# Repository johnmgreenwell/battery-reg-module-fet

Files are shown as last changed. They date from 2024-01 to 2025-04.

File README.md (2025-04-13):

# Battery Regulator Module (N-FET Version)

Custom lithium-polymer battery voltage monitor and regulator module (N-FET version).

## Overview

This custom module is designed as a drop-in for small-scale electronics projects providing 3.3V linear regulated voltage output from a raw lithium polymer cell input. The battery input voltage is monitored by the [MIC2779](https://www.digikey.com/en/products/detail/microchip-technology/MIC2779L-2YM5-TR/1616864) whose output enables or disables the regulated output supply. It is configured with hysteresis to cutoff output when the battery voltage reaches 3.1V and to then hold in reset until the battery voltage exceeds 3.6V.

This is a form-factor-compatible replacement for the battery regulator module design available [here](https://github.com/johnmgreenwell/battery-reg-module). This version makes use of an N-FET transistor for switching rather than the built-in enable used in the original design. This version is meant to serve as a alternate to be used on the basis of parts-available.

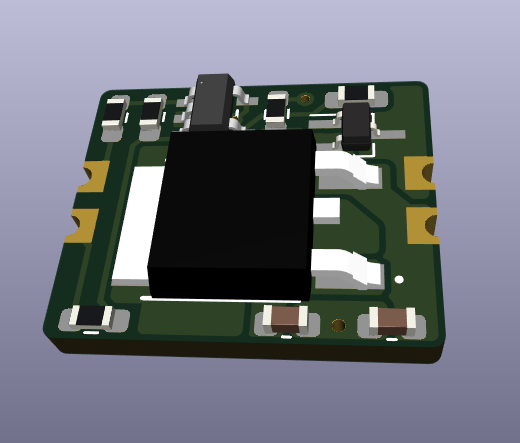
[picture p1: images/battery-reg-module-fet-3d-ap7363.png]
Battery Regulator Module 3d Render


The module supports the 1.5A maximum current limitations of the regulator chip [AP7363](https://www.digikey.com/en/products/detail/diodes-incorporated/AP7363-33D-13/3829401) used.

This module may be combined with a Lipo charger module such as the [TP4056](https://www.best-microcontroller-projects.com/tp4056.html) (along with any in-circuit charging mods as required) for a complete custom battery charging/monitoring/regulation for small-scale electronics projects.

The zipped gerber files provided may be uploaded to a PCB manufacturer for fabrication. Below is the automatic rendering of the uploaded gerbers by [OSHPark](https://oshpark.com/home).

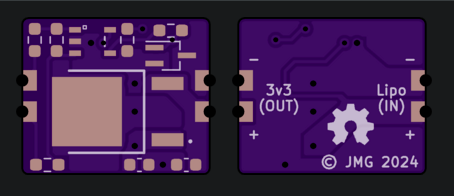
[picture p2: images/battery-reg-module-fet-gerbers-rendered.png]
Battery Regulator Module FET Gerbers Rendered


## Schematic

The schematic for the circuit is provided below as designed in Kicad 9.

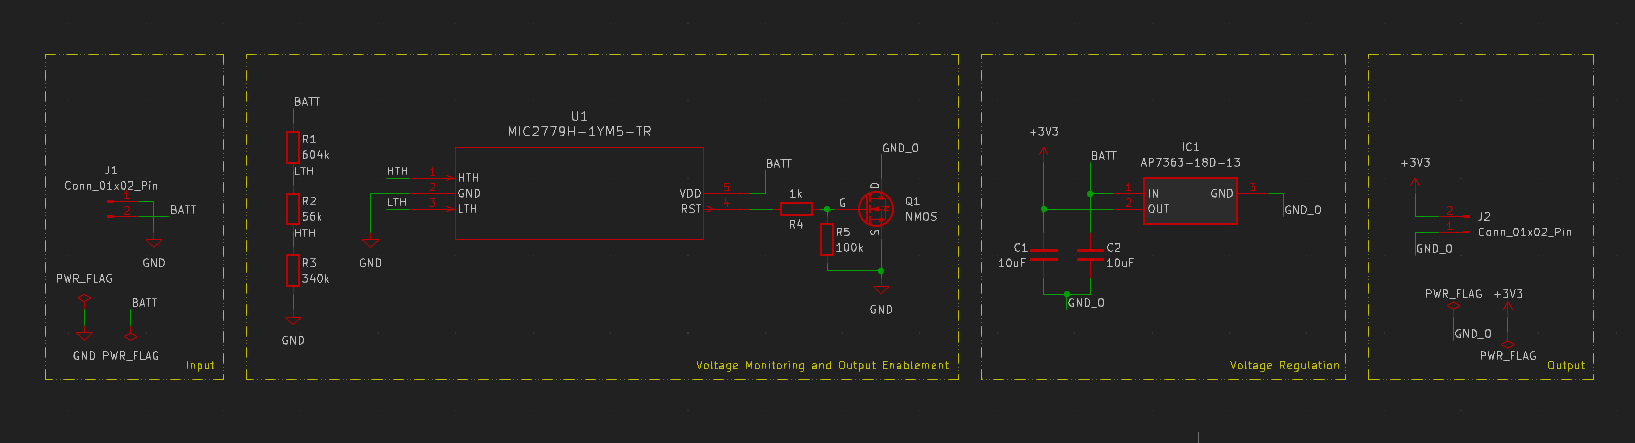
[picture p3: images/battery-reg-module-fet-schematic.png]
Battery Regulator Module Schematic


## License

MIT © 2024 John Greenwell

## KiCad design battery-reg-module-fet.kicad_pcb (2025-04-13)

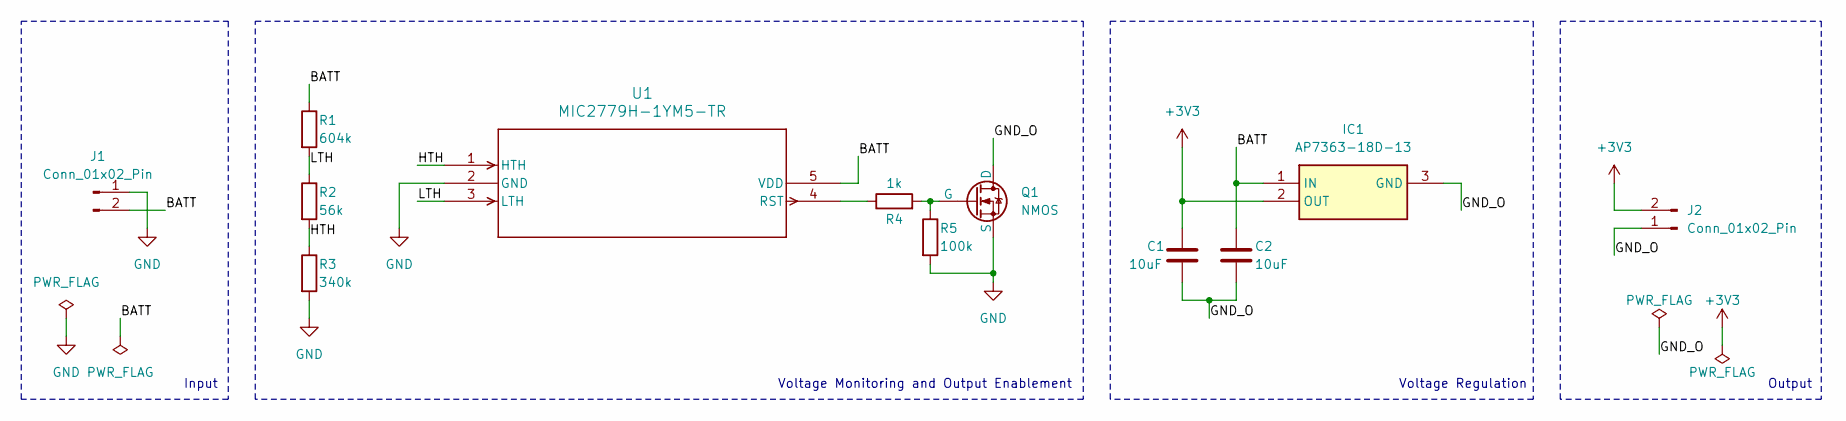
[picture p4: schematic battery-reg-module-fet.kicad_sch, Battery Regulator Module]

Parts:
C1, C2: 10uF; C_0603_1608Metric
IC1: AP7363-18D-13; TO252__DPAK__1; Manufacturer_Part_Number AP7363-18D-13; Mouser Part Number 621-AP7363-18D-13
J1, J2: Conn_01x02_Pin; PinHeader_1x02_P2.54mm_Vertical
Q1: NMOS; SOT-323_SC-70_Handsoldering
R1: 604k; R_0603_1608Metric_Pad0.98x0.95mm_HandSolder
R2: 56k; R_0603_1608Metric_Pad0.98x0.95mm_HandSolder
R3: 340k; R_0603_1608Metric_Pad0.98x0.95mm_HandSolder
R4: 1k; R_0603_1608Metric_Pad0.98x0.95mm_HandSolder
R5: 100k; R_0603_1608Metric_Pad0.98x0.95mm_HandSolder
U1: MIC2779H-1YM5-TR; SOT-23-5_M5_MCH-L

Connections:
+3V3: C1.1, IC1.2 (OUT), J2.2
/BATT: C2.1, IC1.1 (IN), J1.2, R1.1, U1.5 (VDD)
/GND_O: C1.2, C2.2, IC1.3 (GND), J2.1, Q1.1 (D)
/HTH: R2.2, R3.1, U1.1 (HTH)
/LTH: R1.2, R2.1, U1.3 (LTH)
GND: J1.1, Q1.3 (S), R3.2, R5.2, U1.2 (GND)
unnamed: Q1.2 (G), R4.2, R5.1
unnamed: R4.1, U1.4 (RST)

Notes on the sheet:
Voltage Regulation
Input
Output
Voltage Monitoring and Output Enablement

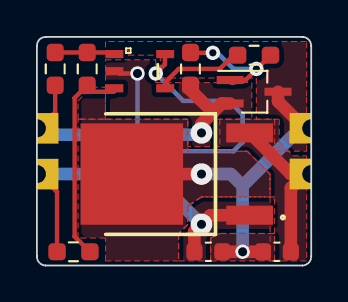
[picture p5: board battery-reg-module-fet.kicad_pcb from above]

Board: 2 copper layers, 15.2 x 12.7 mm, 12 parts (0 on the bottom side), 8 nets.

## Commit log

2024-02-14 Add gerbers, image of gerber rendering
2024-09-27 Update cad files for kicad 8
    [battery-reg-module-fet.kicad_pcb, battery-reg-module-fet.kicad_sch]
2025-04-13 Update cad files to kicad 9
    [battery-reg-module-fet.kicad_pcb, battery-reg-module-fet.kicad_sch]
2025-04-13 Update readme to reference kicad 9

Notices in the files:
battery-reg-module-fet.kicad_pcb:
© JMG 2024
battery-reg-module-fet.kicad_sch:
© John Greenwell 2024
